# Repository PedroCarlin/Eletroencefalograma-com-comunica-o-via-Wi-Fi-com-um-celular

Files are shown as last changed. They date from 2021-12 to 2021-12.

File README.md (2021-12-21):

# Eletroencefalograma que adquiri e envia os dados via Wi-Fi para um celular
Projeto para construir um eletroencefalograma que faz a aquisição e envia o sinal para o celular, mostrando em um gráfico o sinal captado da eletroencefalografia.

Esse sistema é composto por duas placas, responsáveis por fazer a aquisição do sinal da eletroencefalografia (EEG), e por um ESP32 que é responsável por enviar os dados para o celular e armazenar a página web que irá montar o gráfico que representa o sinal do EEG.

Está disponível nesse repositório os arquivos necessários para construir as placas de aquisição e os códigos usados para programar o ESP32 e a página web.

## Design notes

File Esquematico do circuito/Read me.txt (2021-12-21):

O esquemático do circuito foi feito no software TI-Tina da Texas Instruments

Nesse software é possível testar o circuito

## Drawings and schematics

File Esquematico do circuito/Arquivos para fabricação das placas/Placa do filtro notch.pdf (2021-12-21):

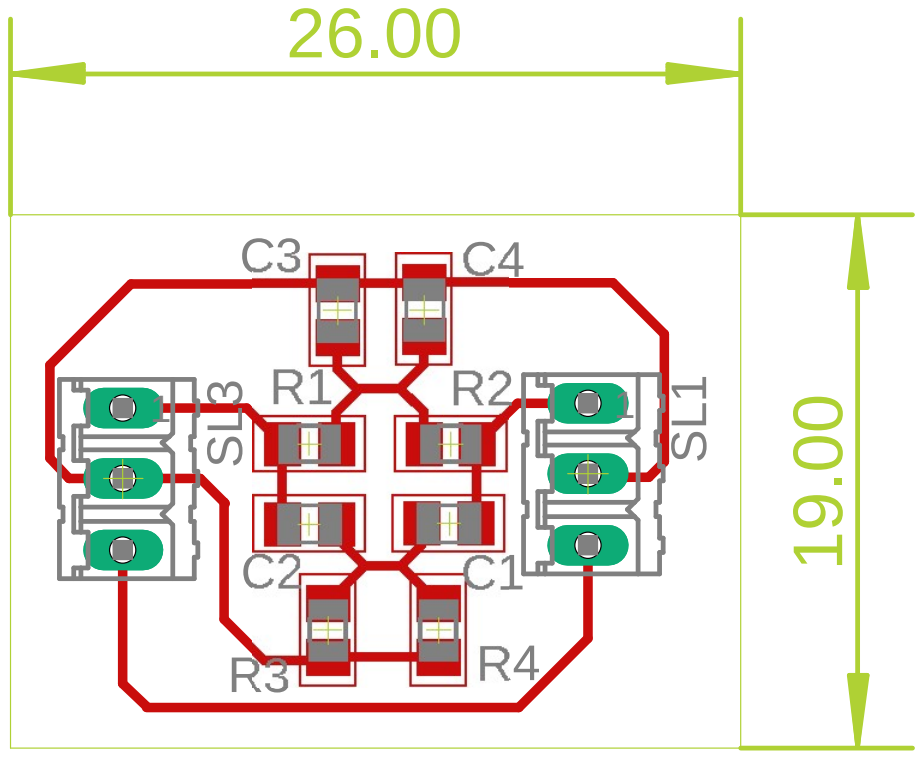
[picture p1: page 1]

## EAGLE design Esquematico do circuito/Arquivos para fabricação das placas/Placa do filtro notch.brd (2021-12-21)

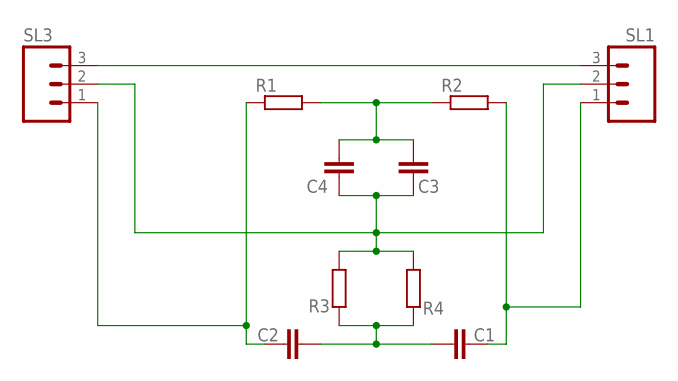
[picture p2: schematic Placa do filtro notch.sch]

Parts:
C1, C2, C3, C4: C-EUC0805; C0805
R1, R2, R3, R4: R-EU_R0805; R0805
SL1, SL3: M03; 03P

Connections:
unnamed: C1.2, C2.2, R3.2, R4.2
unnamed: C2.1, R1.1, SL3.1
unnamed: C3.1, C4.1, R3.1, R4.1, SL1.2, SL3.2
unnamed: C1.1, R2.2, SL1.1
unnamed: C3.2, C4.2, R1.2, R2.1
VCC: SL1.3, SL3.3

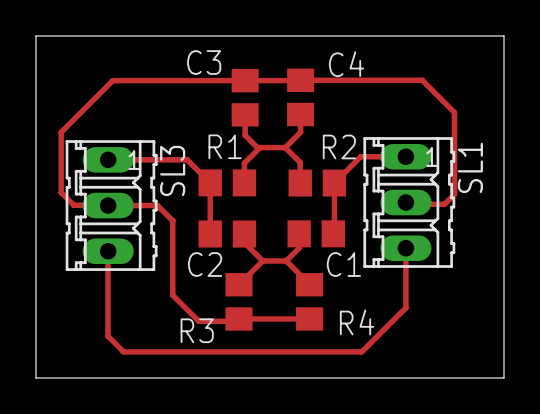
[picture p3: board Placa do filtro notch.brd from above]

Board: 2 copper layers, 26.0 x 19.0 mm, 10 parts (0 on the bottom side), 6 nets.

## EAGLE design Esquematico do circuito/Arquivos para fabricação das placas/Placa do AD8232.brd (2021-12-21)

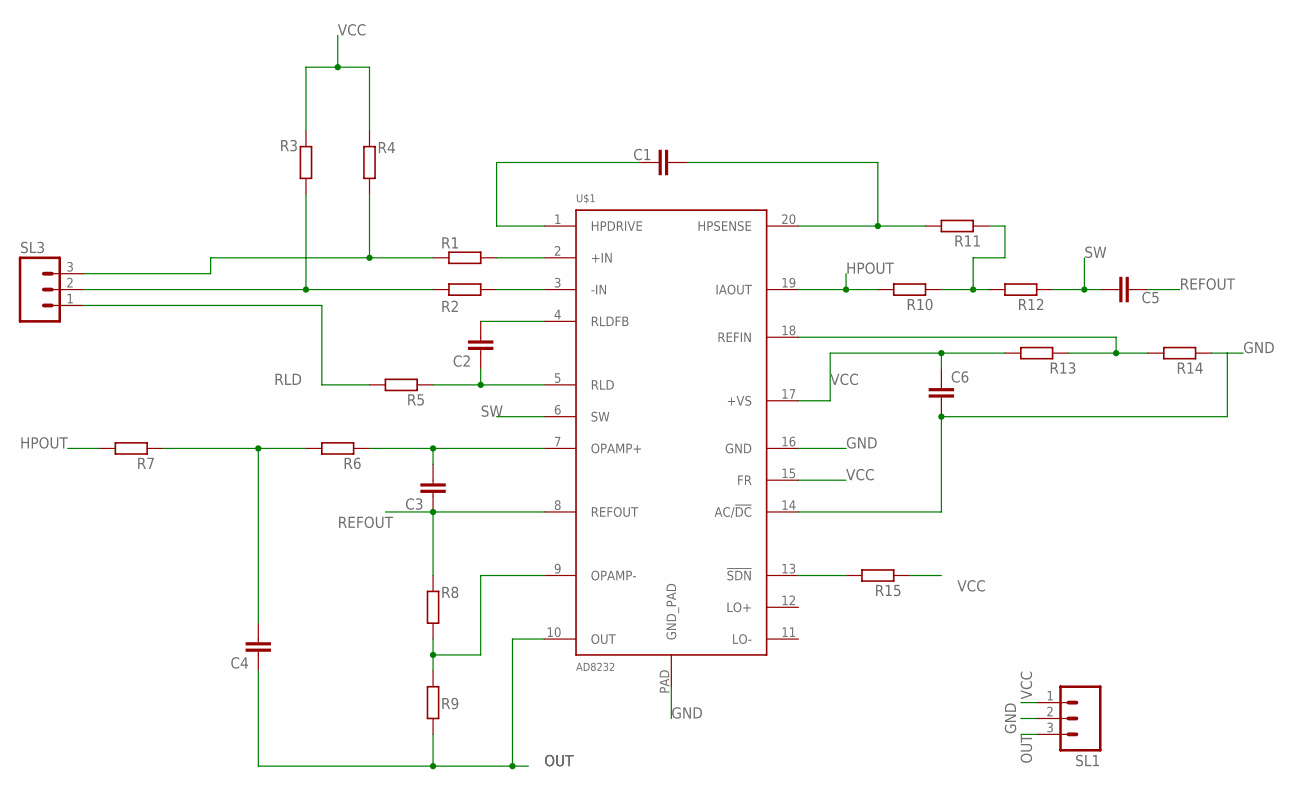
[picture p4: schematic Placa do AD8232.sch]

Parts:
C1, C2, C3, C4, C5, C6: C-EUC0805; C0805
R1, R2, R3, R4, R5, R6, R7, R8, R9, R10, R11, R12, R13, R14, R15: R-EU_R0805; R0805
SL1, SL3: M03; 03P
U$1: AD8232; LFCSP_20

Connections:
GND: C6.2, R14.1, SL1.2, U$1.14 (AC/!DC), U$1.16 (GND), U$1.PAD (GND_PAD)
HPOUT: R7.2, R10.2, U$1.19 (IAOUT)
unnamed: C1.1, U$1.1 (HPDRIVE)
unnamed: C1.2, R11.2, U$1.20 (HPSENSE)
unnamed: R1.2, U$1.2 (+IN)
unnamed: R2.2, U$1.3 (-IN)
unnamed: R1.1, R4.1, SL3.3
unnamed: R2.1, R3.1, SL3.2
unnamed: C2.2, U$1.4 (RLDFB)
unnamed: C2.1, R5.1, U$1.5 (RLD)
unnamed: C3.2, R6.1, U$1.7 (OPAMP+)
unnamed: R13.1, R14.2, U$1.18 (REFIN)
unnamed: R8.2, R9.1, U$1.9 (OPAMP-)
unnamed: R10.1, R11.1, R12.2
unnamed: C4.2, R6.2, R7.1
unnamed: R15.2, U$1.13 (!SDN)
OUT: C4.1, R9.2, SL1.3, U$1.10 (OUT)
REFOUT: C3.1, C5.1, R8.1, U$1.8 (REFOUT)
RLD: R5.2, SL3.1
SW: C5.2, R12.1, U$1.6 (SW)
VCC: C6.1, R3.2, R4.2, R13.2, R15.1, SL1.1, U$1.15 (FR), U$1.17 (+VS)

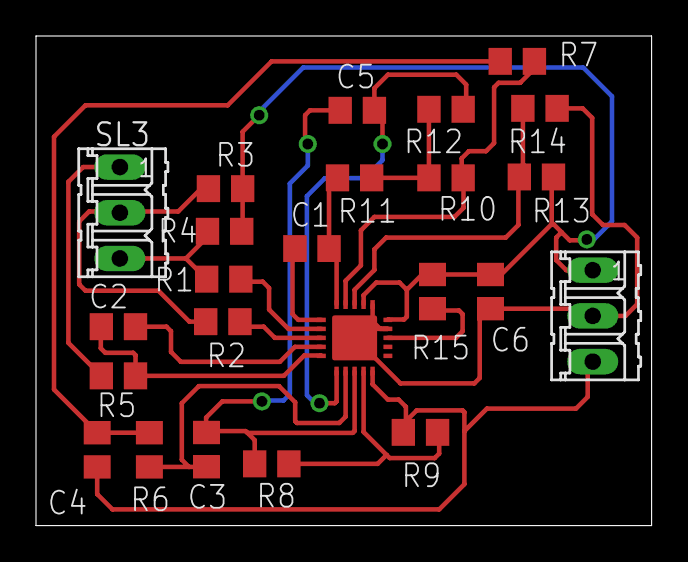
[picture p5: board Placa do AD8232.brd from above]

Board: 2 copper layers, 34.2 x 27.2 mm, 24 parts (0 on the bottom side), 21 nets.

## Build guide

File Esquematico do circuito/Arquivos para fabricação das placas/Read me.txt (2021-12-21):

Os arquivos foram feitos no Eagle, software da Autodesk

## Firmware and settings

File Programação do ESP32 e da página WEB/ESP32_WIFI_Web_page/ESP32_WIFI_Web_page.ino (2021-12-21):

  //Bibliotecas usadas
  #include <WiFi.h>
  #include <ESPAsyncWebServer.h>
  #include <SPIFFS.h>

  //Entrada analogica usada para ligar a placa de aquisição ao ESP32
  #define entradaAnalog 32

  //Nome e senha do wifi, na qual o ESP32 vai se conectar
  const char* ssid = "NOME_DO_WIFI";
  const char* password = "SENHA_DO_WIFI";

  //Cria o servidor para hospedar a página web
  AsyncWebServer server(80);

  // Criar a tarefa que será rodada no segundo núcleo de processamento do ESP32
  TaskHandle_t Task1;
  
  int valor; 
  String dado = "";
  int flag = 0;
  
  void setup() {
    Serial.begin(115200);

    //Inicializa o sistema SPIFFS
    //OBS: É necessario instalar o SPIFFS na IDE do Arduino para usá-lo
    if (!SPIFFS.begin()) {
      Serial.println("An Error has occurred while mounting SPIFFS");
      return;
    }

    //Conecta ao wifi
    WiFi.begin(ssid, password);
    while (WiFi.status() != WL_CONNECTED) {
      delay(1000);
      Serial.println("Connecting to WiFi..");
    }

    //Imprimi no monitor serial o IP do ESP32
    //Esse IP é necessario para acessar a página web
    Serial.println(WiFi.localIP());

    //Envia para a página web todos os arquivos necessarios para o seu funcionamento
    //Esses arquivos estão presentes na pasta "data", que está no mesmo diretorio desse arquivo
    server.on("/", HTTP_GET, [](AsyncWebServerRequest * request) {
      request->send(SPIFFS, "/index.html");
    });
    server.on("/data.js", HTTP_GET, [](AsyncWebServerRequest * request) {
      request->send(SPIFFS, "/data.js", "text/javascript");
    });
    server.on("/export-data.js", HTTP_GET, [](AsyncWebServerRequest * request) {
      request->send(SPIFFS, "/export-data.js", "text/javascript");
    });
    server.on("/exporting.js", HTTP_GET, [](AsyncWebServerRequest * request) {
      request->send(SPIFFS, "/exporting.js", "text/javascript");
    });
    server.on("/highcharts.js", HTTP_GET, [](AsyncWebServerRequest * request) {
      request->send(SPIFFS, "/highcharts.js", "text/javascript");
    });
    server.on("/play.png", HTTP_GET, [](AsyncWebServerRequest * request) {
      request->send(SPIFFS, "/play.png", "image/png");
    });
    server.on("/pause.png", HTTP_GET, [](AsyncWebServerRequest * request) {
      request->send(SPIFFS, "/pause.png", "image/png");
    });
    server.on("/restart.png", HTTP_GET, [](AsyncWebServerRequest * request) {
      request->send(SPIFFS, "/restart.png", "image/png");
    });

    //Tarefa responsavél por enviar os dados lidos pela porta analogica para a página web
    server.on("/EEG", HTTP_GET, [](AsyncWebServerRequest * request) {
      flag = 1;
      String DadoEnviado = dado;
      dado = "";
      request->send(200, "text/html", DadoEnviado.c_str());
    });
  
    server.begin();

    //Inicializa o segundo núcleo de processamento
    xTaskCreatePinnedToCore(
                      Task1code,
                      "Task1",
                      10000,
                      NULL,
                      1,
                      &Task1,
                      0);
    delay(500);
  }
  
  //Função que roda no segundo núcleo
  void Task1code( void * pvParameters ){
    Serial.print("Task1 running on core ");
    Serial.println(xPortGetCoreID());

    //Loop infinito
    for(;;){
      //Só entra nessa função se o ESP32 estiver conectado a um wifi e se a página web já tiver requisitado algum dado
      if(WiFi.status() == WL_CONNECTED && flag == 1){
        valor = analogRead(entradaAnalog);
        if (!isnan(valor)) {
          dado += (String)valor;
          dado += " ";
          delay(10);
        }
      }
    } 
  }
  
  //Não precisa de nenhum codigo no loop, pois as requisições da página web são processadas assincronamento no primeiro núcleo e
  //a aquisição de dados é feita na função acima que processa no segundo núcleo
  void loop() {
    
  }
